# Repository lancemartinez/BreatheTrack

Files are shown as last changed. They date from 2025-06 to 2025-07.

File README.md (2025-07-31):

# BreatheTrack

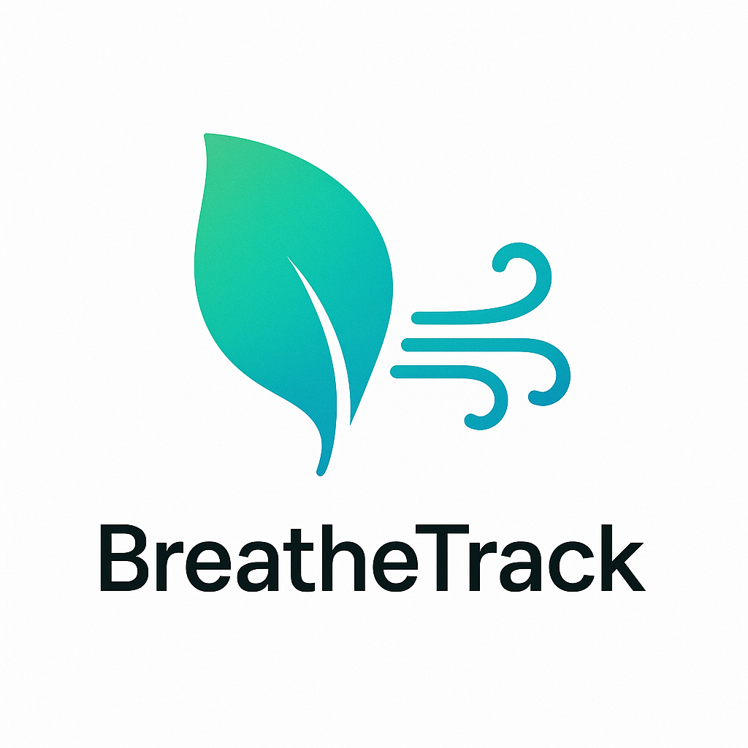
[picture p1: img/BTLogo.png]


## Prototype 1
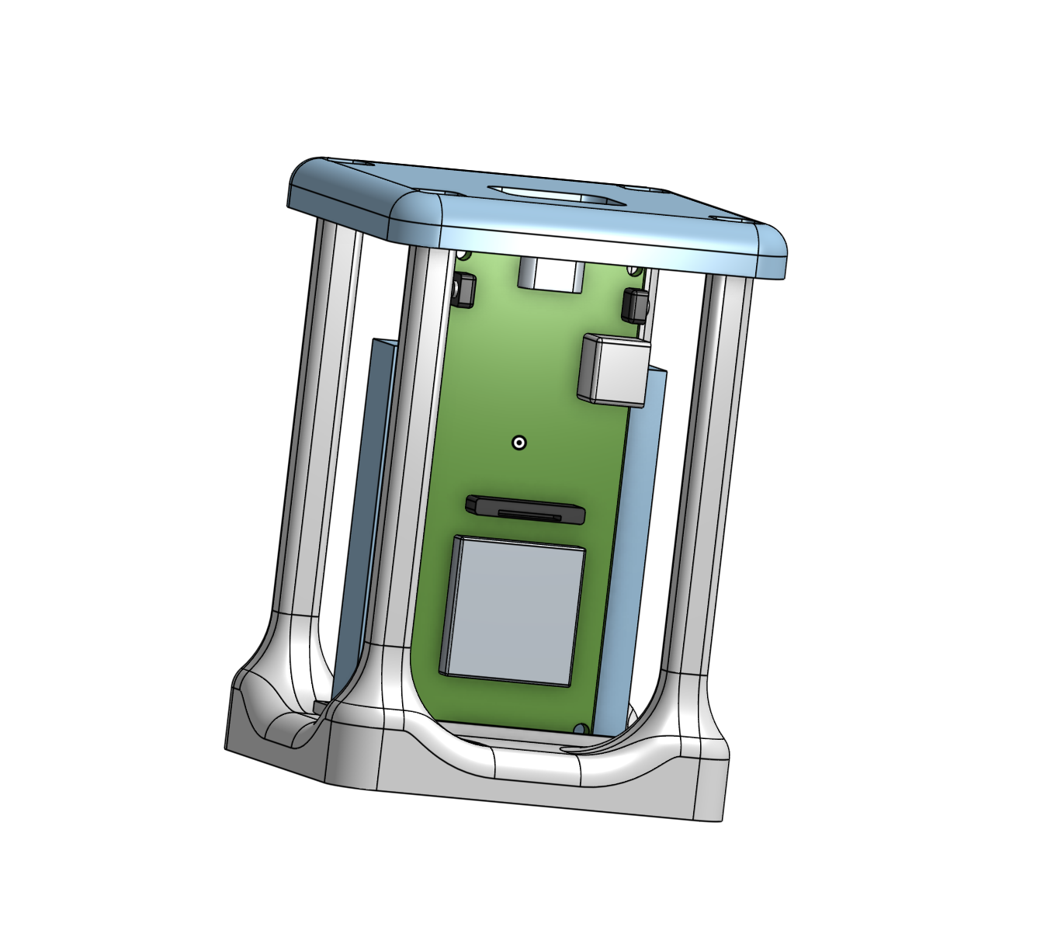
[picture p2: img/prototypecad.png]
CAD


## Assembled Prototype 1 
IRL

## Prototype 2

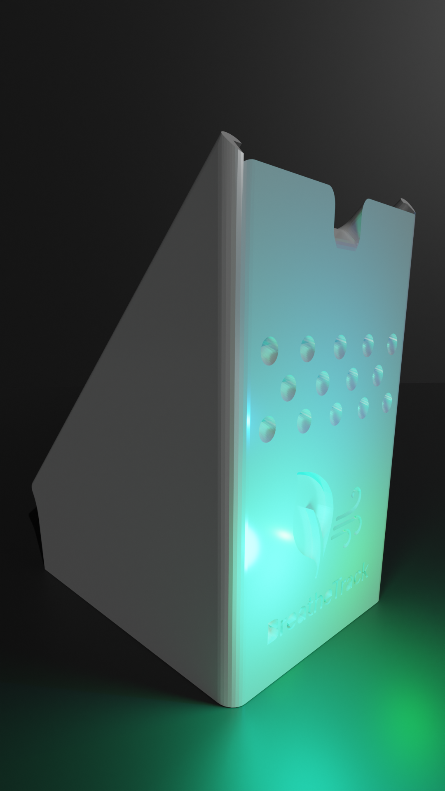
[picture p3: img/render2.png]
Render


## Bill of Materials (BOM)

| Component | Quantity | Price Estimate | Link |
|---|---|---|---|
| PCB | 1 | $60 | [JLCPCB](https://jlcpcb.com) |
| 6V 1W Solar Cell | 5 | $16 | [Amazon](https://www.amazon.com/gp/product/B0BML3PR4Z/ref=ox_sc_act_title_1?smid=A2MJCDED57HY1D&th=1) |
| MakerFocus ESP32 LoRa V3 Dev Board (with 2x SX1262 + 2x Battery) | 1 | $53 | [Amazon](https://www.amazon.com/gp/product/B0DMSGL2DC/ref=ox_sc_act_title_1?smid=A1N6DLY3NQK2VM&th=1) |
| Solar Panel Power Manager | 1 | $14 | [Amazon](https://www.amazon.com/gp/product/B07MML4YJV/ref=ox_sc_act_title_4?smid=A2EH5PO307BR7O&psc=1) |
| Breadboard, Resistors, LEDs Kit | 1 | $10 | [Amazon](https://www.amazon.com/dp/B01ERP6WL4) |
| Soldering Iron | 1 | $9 | [Amazon](https://www.amazon.com/Soldering-Welding-Portable-Electric-Repairing/dp/B098JD8HD3) |
| Total | 10 | $162 | N/A |

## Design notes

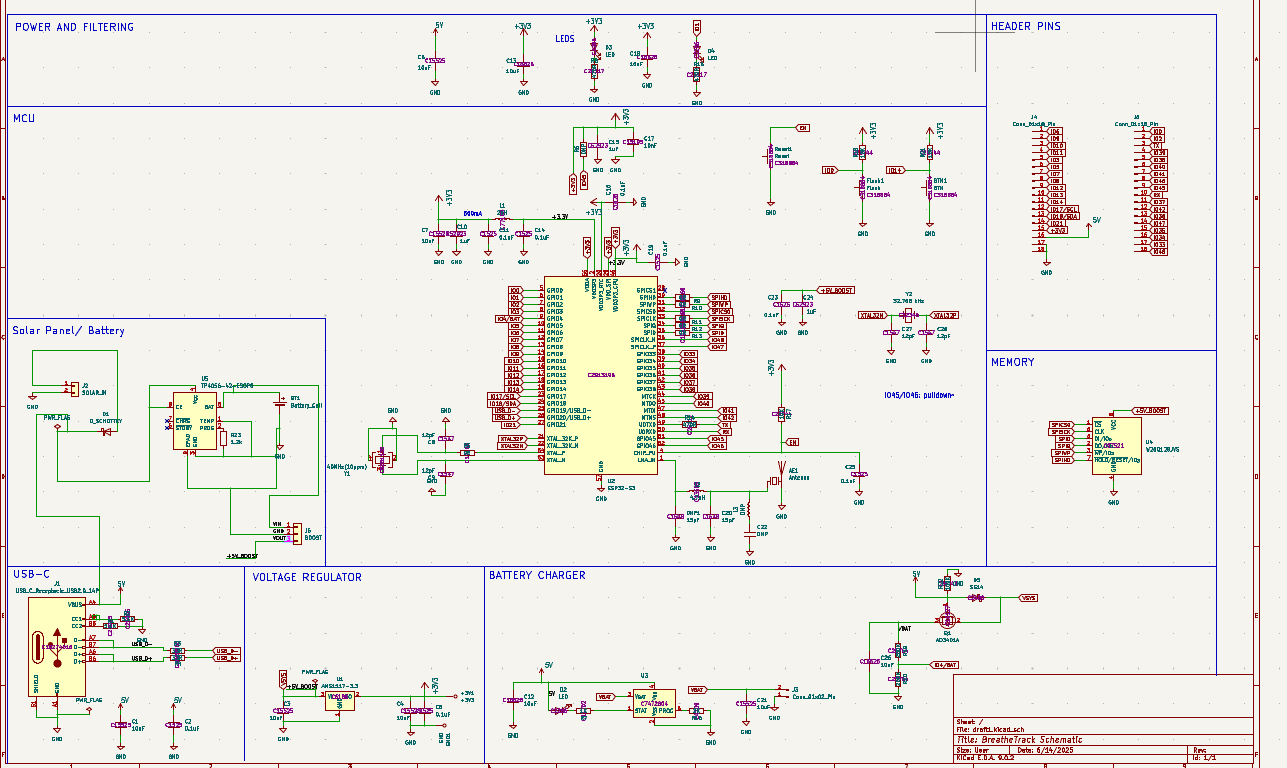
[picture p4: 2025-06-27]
img/schematic.png

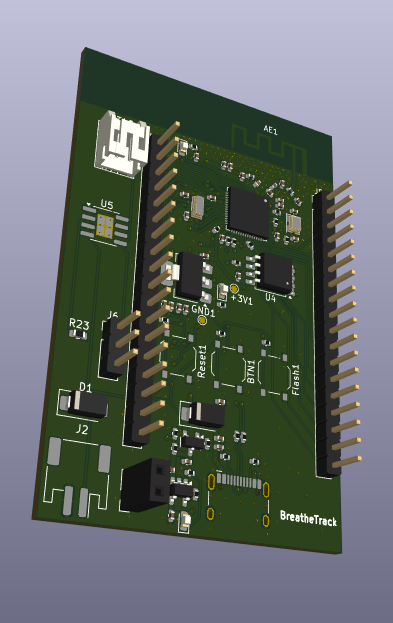
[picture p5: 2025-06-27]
img/BreatheTrackBoard.png

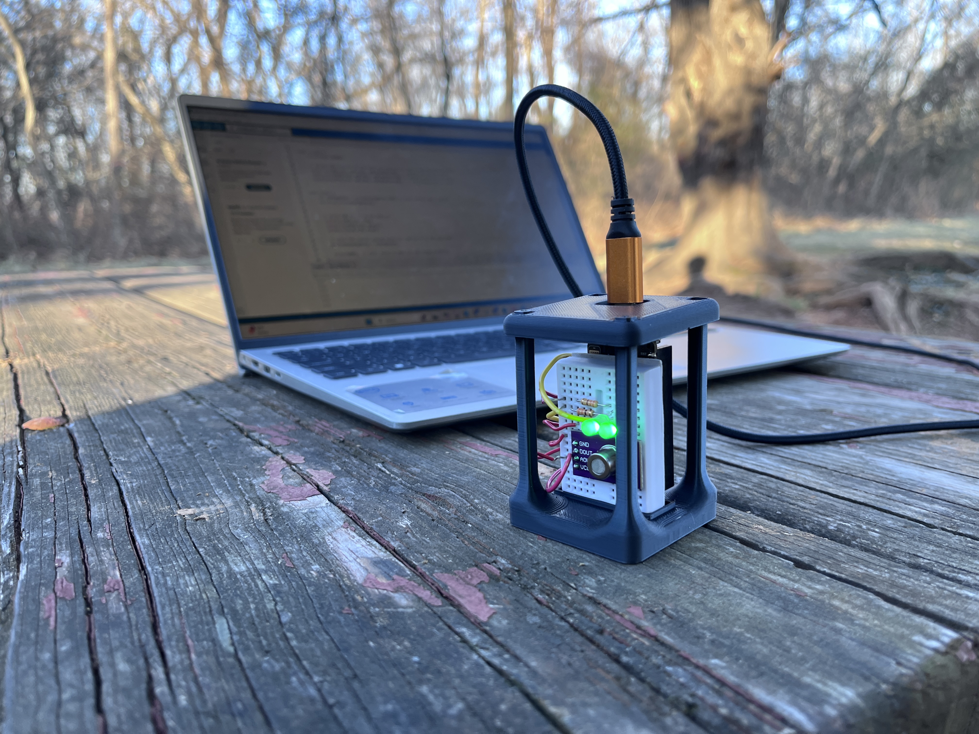
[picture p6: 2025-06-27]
img/prototype.JPG

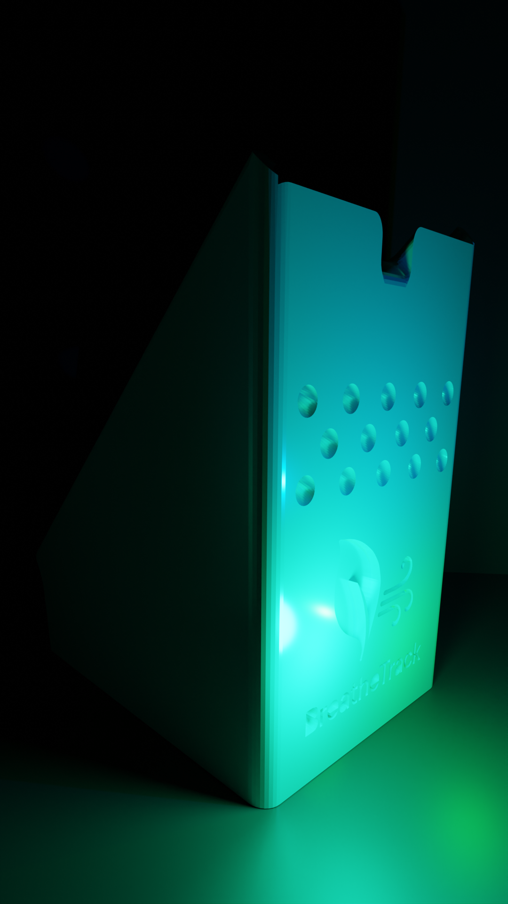
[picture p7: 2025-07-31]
img/render.png

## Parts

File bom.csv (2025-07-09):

Component | Quantity | Price Estimate | Link
PCB | 1 | $60 | https://jlcpcb.com
6V 1W Solar Cell | 5 | $16 | https://www.amazon.com/gp/product/B0BML3PR4Z/ref=ox_sc_act_title_1?smid=A2MJCDED57HY1D&th=1
MakerFocus ESP32 LoRa V3 Dev Board (with 2x SX1262 + 2x Battery) | 1 | $53 | https://www.amazon.com/gp/product/B0DMSGL2DC/ref=ox_sc_act_title_1?smid=A1N6DLY3NQK2VM&th=1
Solar Panel Power Manager | 1 | $14 | https://www.amazon.com/gp/product/B07MML4YJV/ref=ox_sc_act_title_4?smid=A2EH5PO307BR7O&psc=1
Breadboard, Resistors, LEDs Kit | 1 | $10 | https://www.amazon.com/dp/B01ERP6WL4
Soldering Iron | 1 | $9 | https://www.amazon.com/Soldering-Welding-Portable-Electric-Repairing/dp/B098JD8HD3
Total | 10 | $162 | N/A

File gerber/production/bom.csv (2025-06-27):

Designator | Footprint | Quantity | Value | LCSC Part #
+3V1 | TestPoint_Pad_D1.0mm | 1 | +3V3
AE1 | Texas_SWRA117D_2.4GHz_Left | 1 | Antenna
BT1 | JST_PH_S2B-PH-K_1x02_P2.00mm_Horizontal | 1 | Battery_Cell
BTN1 | SW_Push_1P1T_XKB_TS-1187A | 1 | BTN | C318884
C1, C12, C13, C18, C21, C26, C3, C4, C6, C7 | 0402 | 10 | 10uF | C15525
C10, C15, C24 | 0402 | 3 | 1uF | C52923
C11, C14, C16, C19, C2, C23, C25, C5 | 0402 | 8 | 0.1uF | C1525
C17 | 0402 | 1 | 10nF | C15195
C20, DNP1 | 0402 | 2 | 15pF | C1548
C22, L3 | 0402 | 2 | DNP
C27, C28, C8, C9 | 0402 | 4 | 12pF | C1547
D1 | D_SMA | 1 | D_SCHOTTKY
D2, D3, D4 | 0603 | 3 | LED | C2286
D5 | D_SMA | 1 | SS14 | C2480
FLASH1 | SW_Push_1P1T_XKB_TS-1187A | 1 | Flash | C318884
GND1 | TestPoint_Pad_D1.0mm | 1 | GND
J1 | USB_C_Receptacle_HCTL_HC-TYPE-C-16P-01A | 1 | USB_C_Receptacle_USB2.0_14P | C19274016
J2 | JST_PH_S2B-PH-SM4-TB_1x02-1MP_P2.00mm_Horizontal | 1 | SOLAR_IN
J3 | PinSocket_1x02_P2.54mm_Vertical | 1 | Conn_01x02_Pin
J4, J5 | PinHeader_1x18_P2.54mm_Vertical | 2 | Conn_01x18_Pin
J6 | PinHeader_1x03_P2.54mm_Vertical | 1 | BOOST
L1 | 0402 | 1 | 2nH | C77103
L2 | 0402 | 1 | 4.7nH | C13595
Q1 | SOT-23 | 1 | AO3401A | C15127
R1, R2 | 0402 | 2 | 5.1K | C25905
R10, R11, R12, R13, R5, R9 | 0402 | 6 | 0R | C17168
R14, R15, R8 | 0402 | 3 | 470R | C25117
R16 | 0402 | 1 | 2K | C4109
R17, R18, R21 | 0402 | 3 | 10K | C25744
R19, R20 | 0402 | 2 | 200K | C25764
R22 | 0402 | 1 | 100K | C25741
R23 | 0603 | 1 | 1.2k
R3, R4 | 0402 | 2 | 33R | C25105
R6 | 0402 | 1 | DNP
R7 | 0402 | 1 | 1K | C11702
RESET1 | SW_Push_1P1T_XKB_TS-1187A | 1 | Reset | C318884
U1 | SOT-223-3_TabPin2 | 1 | AMS1117-3.3 | C6186
U2 | QFN-56-1EP_7x7mm_P0.4mm_EP4x4mm | 1 | ESP32-S3 | C2913194
U3 | SOT-23-5 | 1 | MCP73831-2-OT | C7472804
U4 | SOIC-8_5.3x5.3mm_P1.27mm | 1 | W25Q128JVS | C97521
U5 | SOIC-8-1EP_3.9x4.9mm_P1.27mm_EP2.41x3.3mm_ThermalVias | 1 | TP4056-42-ESOP8
Y1 | Crystal_SMD_2520-4Pin_2.5x2.0mm | 1 | 40MHz(10ppm) | C5261125
Y2 | Crystal_SMD_3215-2Pin_3.2x1.5mm | 1 | 32.768 kHz | C32346

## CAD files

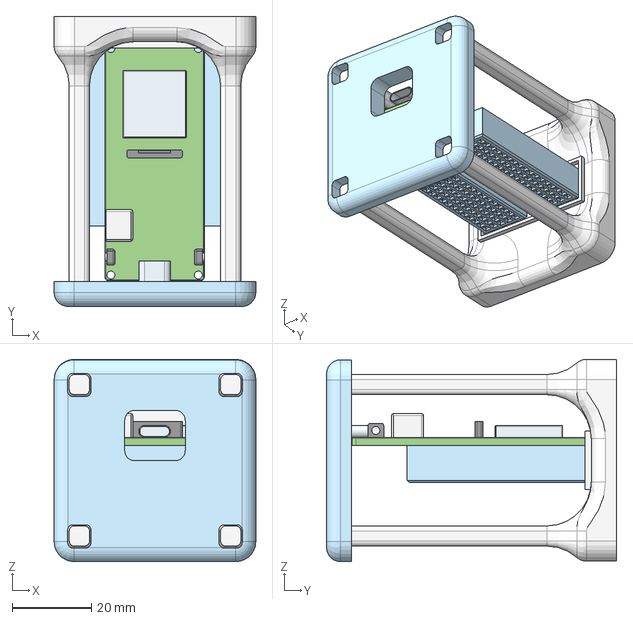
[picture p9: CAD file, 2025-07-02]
cad/full.step
50.8 x 73.0 x 50.9 mm
FireBeetle ESP32

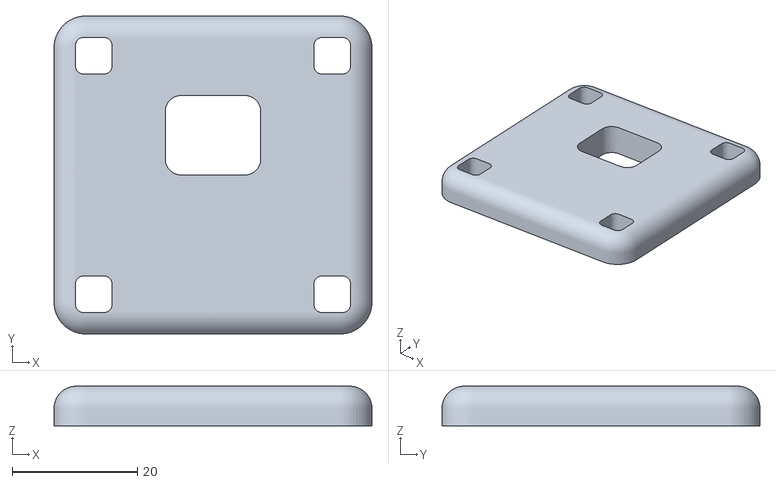
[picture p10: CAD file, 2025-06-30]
cad/top.stl
50.8 x 50.8 x 6.35

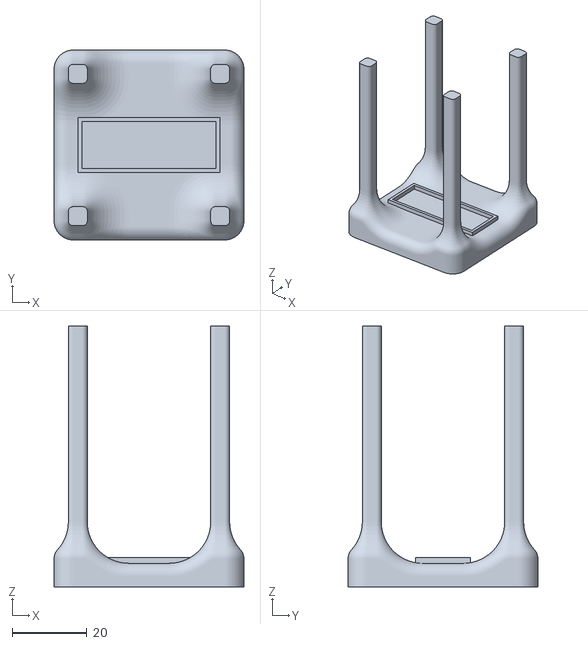
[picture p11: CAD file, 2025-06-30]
cad/base.stl
50.8 x 50.8 x 69.8

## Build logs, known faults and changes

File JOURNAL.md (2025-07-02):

---
title: "BreatheTrack Solar‑Powered PCB Design"
author: "Lance Martinez"
description: "Solar panel, battery charger, protection, and boost stages to power our custom ESP32‑AQI sensor board from sunlight alone."
created_at: "2025-06-14"
---

## Total Time Spent: ~ 16.5 hours   

### June 3
Time Spent: ~6 hours  

Today, I focused on building the core ESP32 section of our custom PCB in KiCad 9.0. I added all the main headers, supporting components, and filtered power supply for the ESP32. This includes decoupling capacitors, pull-up resistors, and the external crystal to keep the ESP32 stable. This was my first time building something like this, so I carefully checked all the pin assignments and made sure everything matched the microcontroller datasheet.

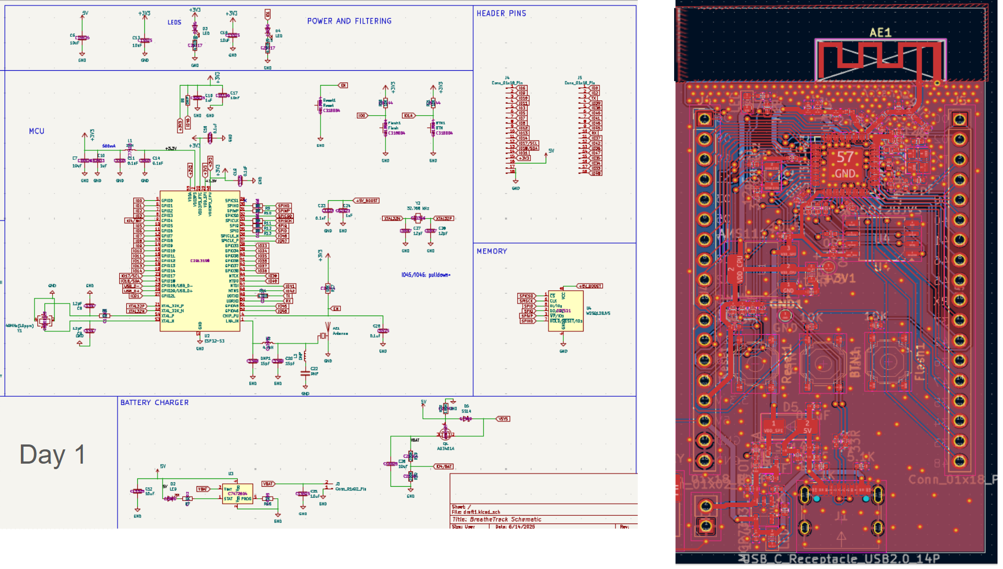
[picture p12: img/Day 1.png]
Day 1


### June 5
Time Spent: ~3 hours  
Today I started adding power management to the board. I wired in the solar panel input with a Schottky diode, connected it to a TP4056 charging IC with battery protection, and then added a boost converter to step up the voltage for the ESP32. I also placed the JST connectors for both the battery and solar panel. Getting all the power paths correct took some troubleshooting, especially routing from the solar panel through the diode into the charger. I made sure everything would pass power safely and avoid battery drain through the panel at night.

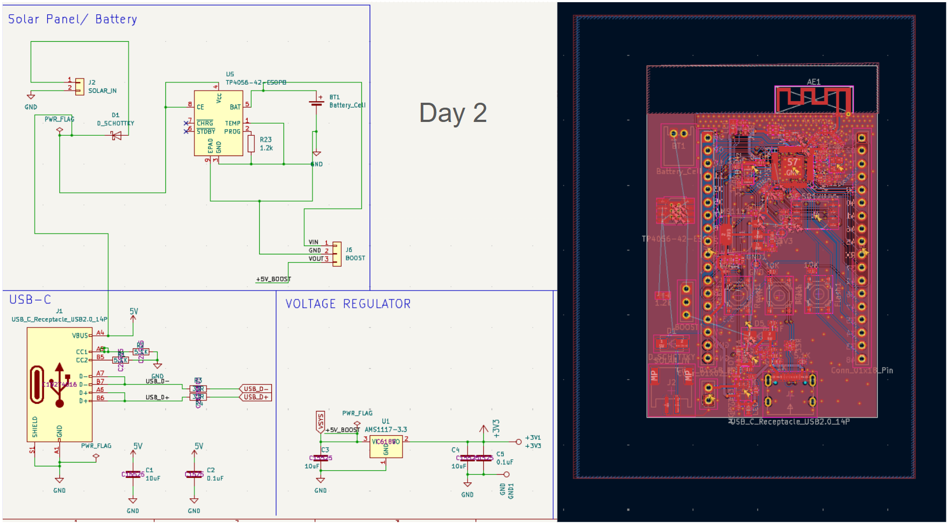
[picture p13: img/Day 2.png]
Day 2


### June 10
Time Spent: ~3 hours  
This day was all about finishing the wiring. I routed power and signal lines for the full system, including the ESP32, USB port, and power modules. I carefully laid out the boost converter output to feed into the ESP32's 5V input rail and added silkscreen labels for clarity. I also added vias and filled in ground planes to reduce noise and improve current return paths. The PCB was becoming more complete and compact, and I started preparing for design rule checks.

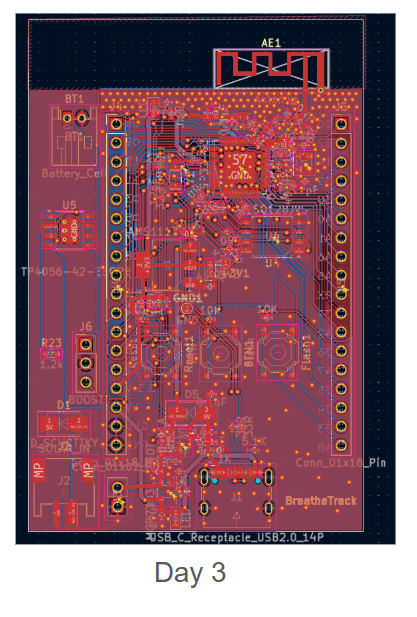
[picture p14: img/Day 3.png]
Day 3


### June 12

Time Spent: ~1.5 hours   

Today, I finalized the 3D-printed enclosure for our system. This case securely holds the ESP32, AQI sensor, and the breadboard containing the circuitry. The design includes precision slots that apply just enough pressure to hold the board firmly in place. The top and bottom covers snap into the frame and leave space for airflow, allowing accurate environmental readings. Building this physical housing was a major step toward making our device ready for outdoor areas.

Prototype CAD

## June 14
Time Spent: ~3 hours  
Today I fixed the final DRC errors and reviewed the board for manufacturing. I checked footprint sizes, confirmed that clearances were good, and ran the 3D viewer for the first time to confirm everything looked right. Seeing the board in 3D helped catch small alignment issues, and I made final tweaks to trace widths and placements. Now, the board is ready to export Gerber files and send for fabrication!

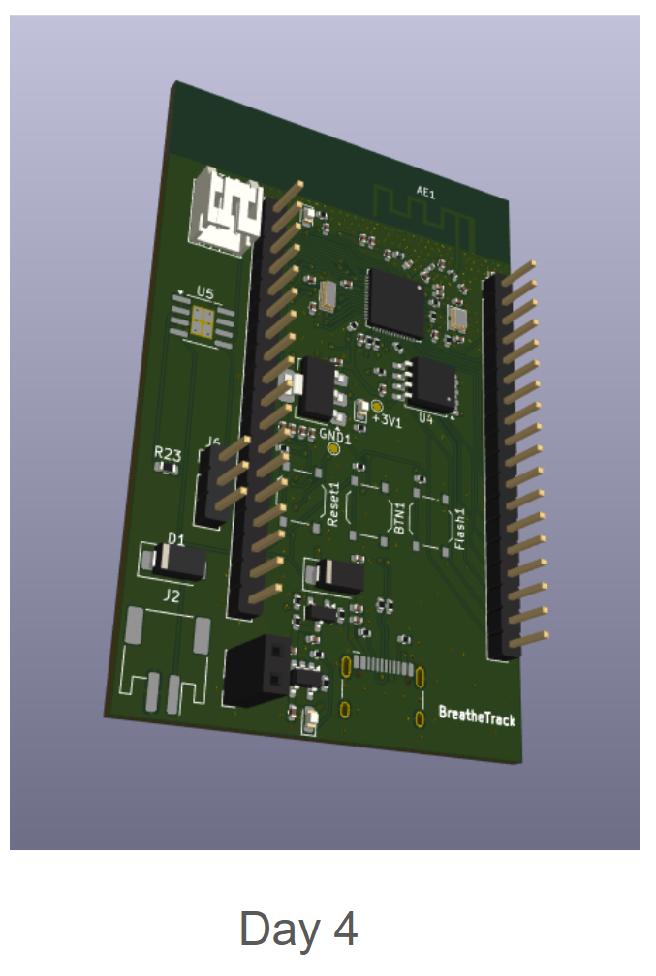
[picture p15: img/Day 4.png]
Day 4


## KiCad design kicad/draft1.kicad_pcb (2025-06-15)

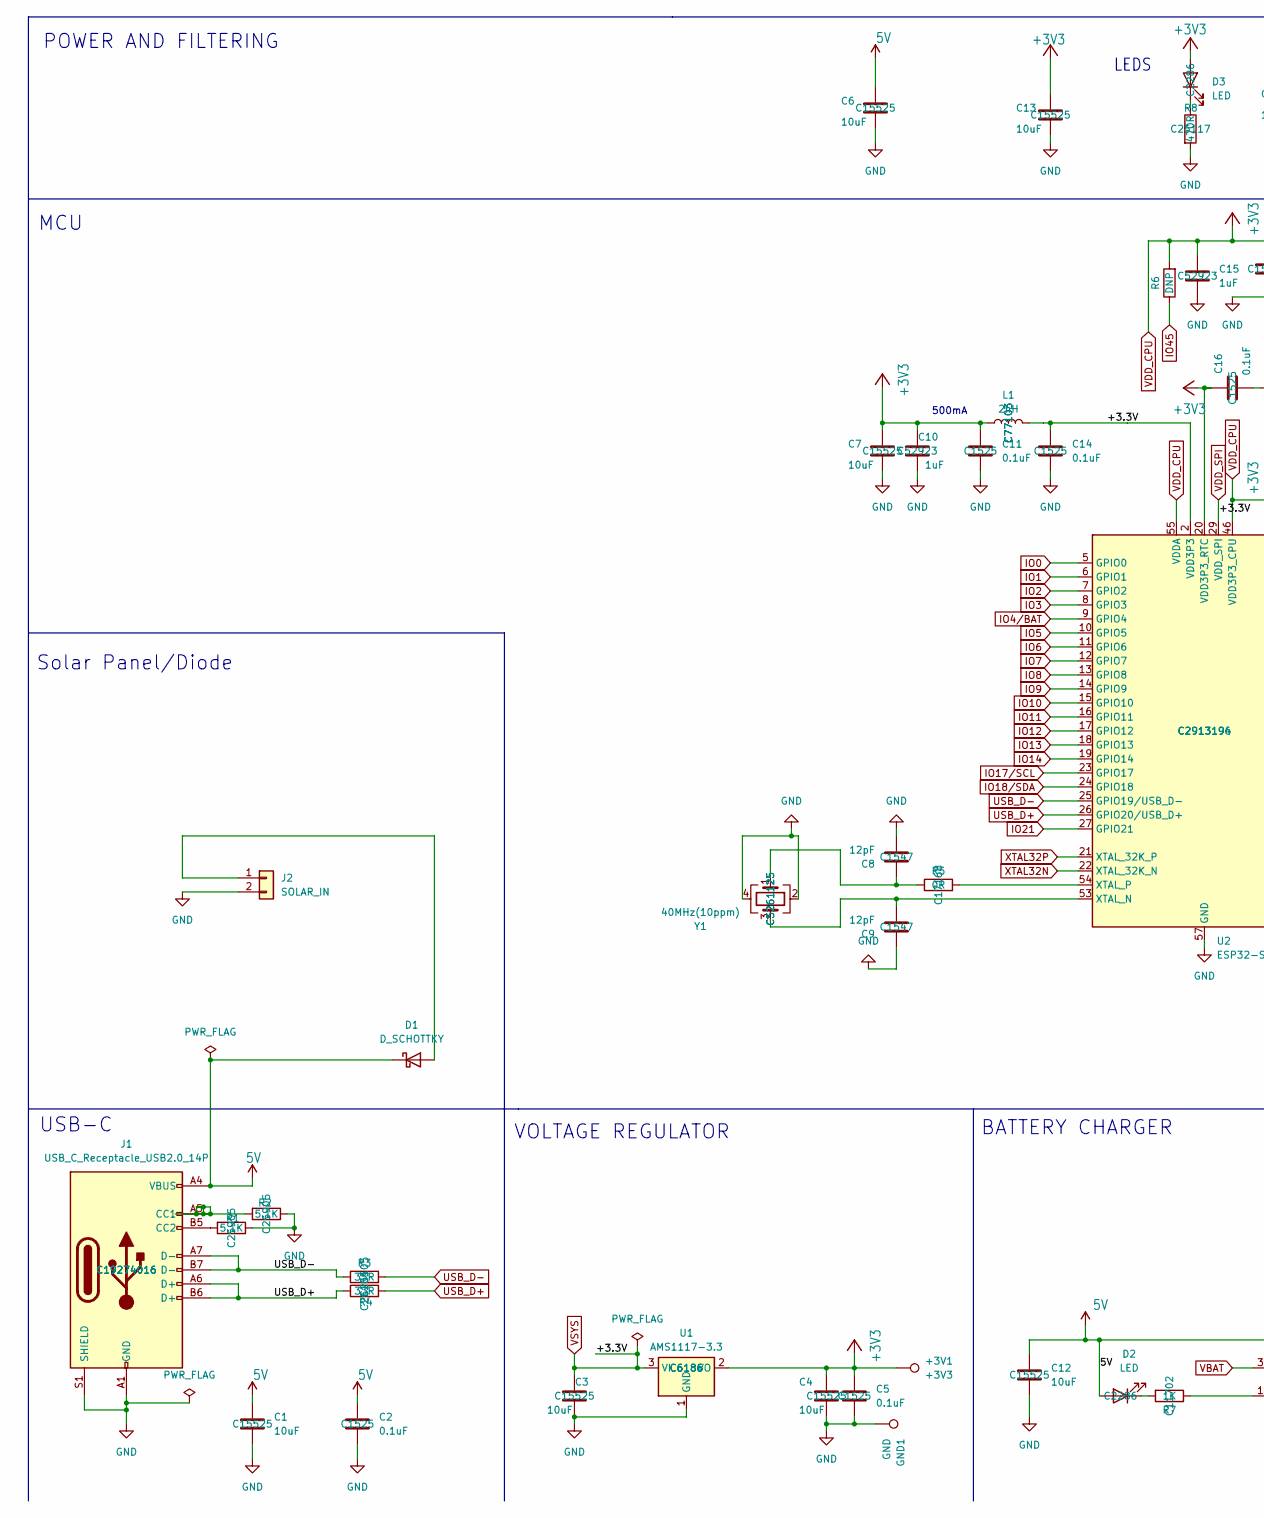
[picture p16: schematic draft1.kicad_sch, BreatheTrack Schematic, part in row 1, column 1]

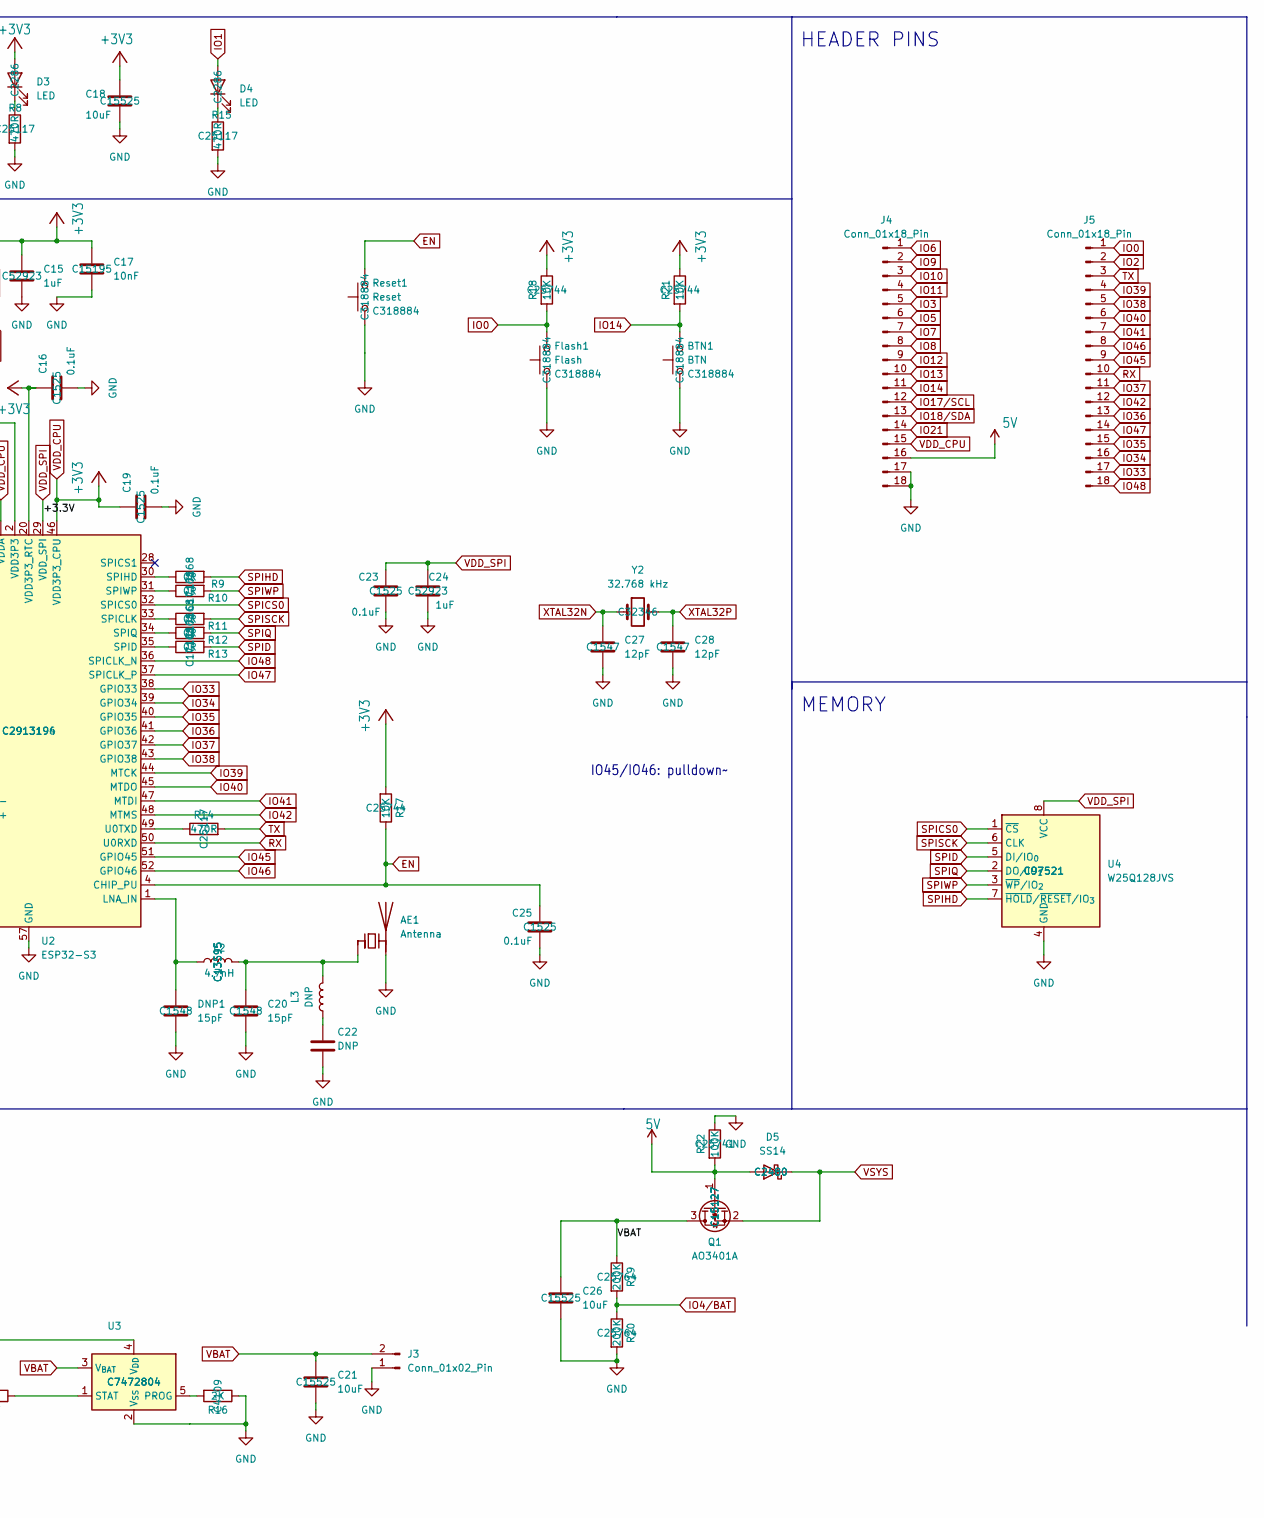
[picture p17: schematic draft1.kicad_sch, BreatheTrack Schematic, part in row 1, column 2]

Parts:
+3V1: +3V3; TestPoint_Pad_D1.0mm
AE1: Antenna; Texas_SWRA117D_2.4GHz_Left
BTN1: BTN; SW_Push_1P1T_XKB_TS-1187A; MNF PART NUMBER C318884; LCSC C318884
C1, C3, C4, C6, C7, C12, C13, C18, C21, C26: 10uF; C_0402_1005Metric; MNF PART NUMBER C15525; LCSC C15525
C2, C5, C11, C14, C16, C19, C23, C25: 0.1uF; C_0402_1005Metric; MNF PART NUMBER C1525; LCSC C1525
C8, C9, C27, C28: 12pF; C_0402_1005Metric; MNF PART NUMBER C1547; LCSC C1547
C10, C15, C24: 1uF; C_0402_1005Metric; MNF PART NUMBER C52923; LCSC C52923
C17: 10nF; C_0402_1005Metric; MNF PART NUMBER C15195; LCSC C15195
C20: 15pF; C_0402_1005Metric; MNF PART NUMBER C1548; LCSC C1548
C22: DNP; C_0402_1005Metric
D1: D_SCHOTTKY; D_SMA
D2, D3, D4: LED; LED_0603_1608Metric; MNF PART NUMBER C2286; LCSC C2286
D5: SS14; D_SMA; MNF PART NUMBER C2480; LCSC C2480
DNP1: 15pF; C_0402_1005Metric; MNF PART NUMBER C1548; LCSC C1548
Flash1: Flash; SW_Push_1P1T_XKB_TS-1187A; MNF PART NUMBER C318884; LCSC C318884
GND1: GND; TestPoint_Pad_D1.0mm
J1: USB_C_Receptacle_USB2.0_14P; USB_C_Receptacle_HCTL_HC-TYPE-C-16P-01A; MNF PART NUMBER C19274016; LCSC C19274016
J2: SOLAR_IN; JST_PH_S2B-PH-SM4-TB_1x02-1MP_P2.00mm_Horizontal
J3: Conn_01x02_Pin; PinSocket_1x02_P2.54mm_Vertical
J4, J5: Conn_01x18_Pin; PinHeader_1x18_P2.54mm_Vertical
L1: 2nH; L_0402_1005Metric; MNF PART NUMBER C77103; LCSC C77103
L2: 4.7nH; L_0402_1005Metric; MNF PART NUMBER C13595; LCSC C13595
L3: DNP; L_0402_1005Metric
Q1: AO3401A; SOT-23; MNF PART NUMBER C15127; LCSC C15127
R1, R2: 5.1K; R_0402_1005Metric; MNF PART NUMBER C25905; LCSC C25905
R3, R4: 33R; R_0402_1005Metric; MNF PART NUMBER C25105; LCSC C25105
R5, R9, R10, R11, R12, R13: 0R; R_0402_1005Metric; MNF PART NUMBER C17168; LCSC C17168
R6: DNP; R_0402_1005Metric
R7: 1K; R_0402_1005Metric; MNF PART NUMBER C11702; LCSC C11702
R8, R14, R15: 470R; R_0402_1005Metric; MNF PART NUMBER C25117; LCSC C25117
R16: 2K; R_0402_1005Metric; MNF PART NUMBER C4109; LCSC C4109
R17, R18, R21: 10K; R_0402_1005Metric; MNF PART NUMBER C25744; LCSC C25744
R19, R20: 200K; R_0402_1005Metric; MNF PART NUMBER C25764; LCSC C25764
R22: 100K; R_0402_1005Metric; MNF PART NUMBER C25741; LCSC C25741
Reset1: Reset; SW_Push_1P1T_XKB_TS-1187A; MNF PART NUMBER C318884; LCSC C318884
U1: AMS1117-3.3; SOT-223-3_TabPin2; MNF PART NUMBER C6186; LCSC C6186
U2: ESP32-S3; QFN-56-1EP_7x7mm_P0.4mm_EP4x4mm; MNF PART NUMBER C2913196; LCSC C2913194
U3: MCP73831-2-OT; SOT-23-5; MNF PART NUMBER C7472804; LCSC C7472804
U4: W25Q128JVS; SOIC-8_5.3x5.3mm_P1.27mm; MNF PART NUMBER C97521; LCSC C97521
Y1: 40MHz(10ppm); Crystal_SMD_2520-4Pin_2.5x2.0mm; MNF PART NUMBER C5261125; LCSC C5261125
Y2: 32.768 kHz; Crystal_SMD_3215-2Pin_3.2x1.5mm; MNF PART NUMBER C32346; LCSC C32346

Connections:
5V: C1.1, C2.1, C6.1, C12.1, D1.1 (K), D2.2 (A), D5.2 (A), J1.A4 (VBUS), J1.A9 (VBUS), J1.B4 (VBUS), J1.B9 (VBUS), J4.16, Q1.1 (G), R22.2, U3.4 (V_{DD})
EN: C25.1, R17.1, Reset1.2, U2.4 (CHIP_PU)
GND: AE1.2 (PCB_Trace), BTN1.1, C1.2, C2.2, C3.2, C4.2, C5.2, C6.2, C7.2, C8.2, C9.1, C10.2, C11.2, C12.2, C13.2, C14.2, C15.2, C16.2, C17.2, C18.2, C19.2, C20.2, C21.2, C22.2, C23.2, C24.2, C25.2, C26.2, C27.2, C28.2, DNP1.2, Flash1.1, GND1.1, J1.A1 (GND), J1.A12 (GND), J1.B1 (GND), J1.B12 (GND), J1.S1 (SHIELD), J2.2, J3.1, J4.17, J4.18, R1.1, R2.1, R8.2, R15.2, R16.1, R20.2, R22.1, Reset1.1, U1.1 (GND), U2.57 (GND), U3.2 (V_{SS}), U4.4 (GND), Y1.2, Y1.4
IO0: Flash1.2, J5.1, R18.2, U2.5 (GPIO0)
IO1: D4.2 (A), U2.6 (GPIO1)
IO2: J5.2, U2.7 (GPIO2)
IO3: J4.5, U2.8 (GPIO3)
IO4/BAT: R19.2, R20.1, U2.9 (GPIO4)
IO5: J4.6, U2.10 (GPIO5)
IO6: J4.1, U2.11 (GPIO6)
IO7: J4.7, U2.12 (GPIO7)
IO8: J4.8, U2.13 (GPIO8)
IO9: J4.2, U2.14 (GPIO9)
IO10: J4.3, U2.15 (GPIO10)
IO11: J4.4, U2.16 (GPIO11)
IO12: J4.9, U2.17 (GPIO12)
IO13: J4.10, U2.18 (GPIO13)
IO14: BTN1.2, J4.11, R21.2, U2.19 (GPIO14)
IO17/SCL: J4.12, U2.23 (GPIO17)
IO18/SDA: J4.13, U2.24 (GPIO18)
IO21: J4.14, U2.27 (GPIO21)
IO33: J5.17, U2.38 (GPIO33)
IO34: J5.16, U2.39 (GPIO34)
IO35: J5.15, U2.40 (GPIO35)
IO36: J5.13, U2.41 (GPIO36)
IO37: J5.11, U2.42 (GPIO37)
IO38: J5.5, U2.43 (GPIO38)
IO39: J5.4, U2.44 (MTCK)
IO40: J5.6, U2.45 (MTDO)
IO41: J5.7, U2.47 (MTDI)
IO42: J5.12, U2.48 (MTMS)
IO45: J5.9, R6.1, U2.51 (GPIO45)
IO46: J5.8, U2.52 (GPIO46)
IO47: J5.14, U2.37 (SPICLK_P)
IO48: J5.18, U2.36 (SPICLK_N)
unnamed: AE1.1 (FEED), C20.1, L2.2, L3.2
unnamed: C8.1, R5.1, Y1.1
unnamed: C22.1, L3.1
unnamed: D1.2 (A), J2.1
unnamed: D2.1 (K), R7.2
unnamed: D3.1 (K), R8.1
unnamed: D4.1 (K), R15.1
unnamed: J1.A5 (CC1), R2.2
unnamed: J1.B5 (CC2), R1.2
unnamed: DNP1.1, L2.1, U2.1 (LNA_IN)
unnamed: R11.1, U2.33 (SPICLK)
unnamed: R13.1, U2.35 (SPID)
unnamed: R9.1, U2.30 (SPIHD)
unnamed: R12.1, U2.34 (SPIQ)
unnamed: R10.1, U2.31 (SPIWP)
unnamed: R14.1, U2.49 (U0TXD)
unnamed: C9.2, U2.53 (XTAL_N), Y1.3
unnamed: R5.2, U2.54 (XTAL_P)
unnamed: R16.2, U3.5 (PROG)
unnamed: R7.1, U3.1 (STAT)
RX: J5.10, U2.50 (U0RXD)
SPICS0: U2.32 (SPICS0), U4.1 (~CS)
SPID: R13.2, U4.5 (DI/IO_{0})
SPIHD: R9.2, U4.7 (~HOLD/~RESET/IO_{3})
SPIQ: R12.2, U4.2 (DO/IO_{1})
SPISCK: R11.2, U4.6 (CLK)
SPIWP: R10.2, U4.3 (~WP/IO_{2})
TX: J5.3, R14.2
USB_D+: J1.A6 (D+), J1.B6 (D+), R4.1, R4.2, U2.26 (GPIO20/USB_D+)
USB_D-: J1.A7 (D-), J1.B7 (D-), R3.1, R3.2, U2.25 (GPIO19/USB_D-)
VBAT: C21.1, C26.1, J3.2, Q1.3 (D), R19.1, U3.3 (V_{BAT})
VDD_CPU: +3V1.1, C4.1, C5.1, C7.1, C10.1, C11.1, C13.1, C15.1, C16.1, C17.1, C18.1, C19.1, D3.2 (A), J4.15, L1.1, R6.2, R17.2, R18.1, R21.1, U1.2 (VO), U2.20 (VDD3P3_RTC), U2.46 (VDD3P3_CPU), U2.55 (VDDA), U2.56 (VDDA)
VDD_SPI: C3.1, C14.1, C23.1, C24.1, D5.1 (K), L1.2, Q1.2 (S), U1.3 (VI), U2.2 (VDD3P3), U2.3 (VDD3P3), U2.29 (VDD_SPI), U4.8 (VCC)
XTAL32N: C27.1, U2.22 (XTAL_32K_N), Y2.1
XTAL32P: C28.1, U2.21 (XTAL_32K_P), Y2.2

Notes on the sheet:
Solar Panel/Diode
500mA
MCU
USB-C
BATTERY CHARGER
MEMORY
VOLTAGE REGULATOR
IO45/IO46: pulldown~~{}
POWER AND FILTERING
HEADER PINS
LEDS

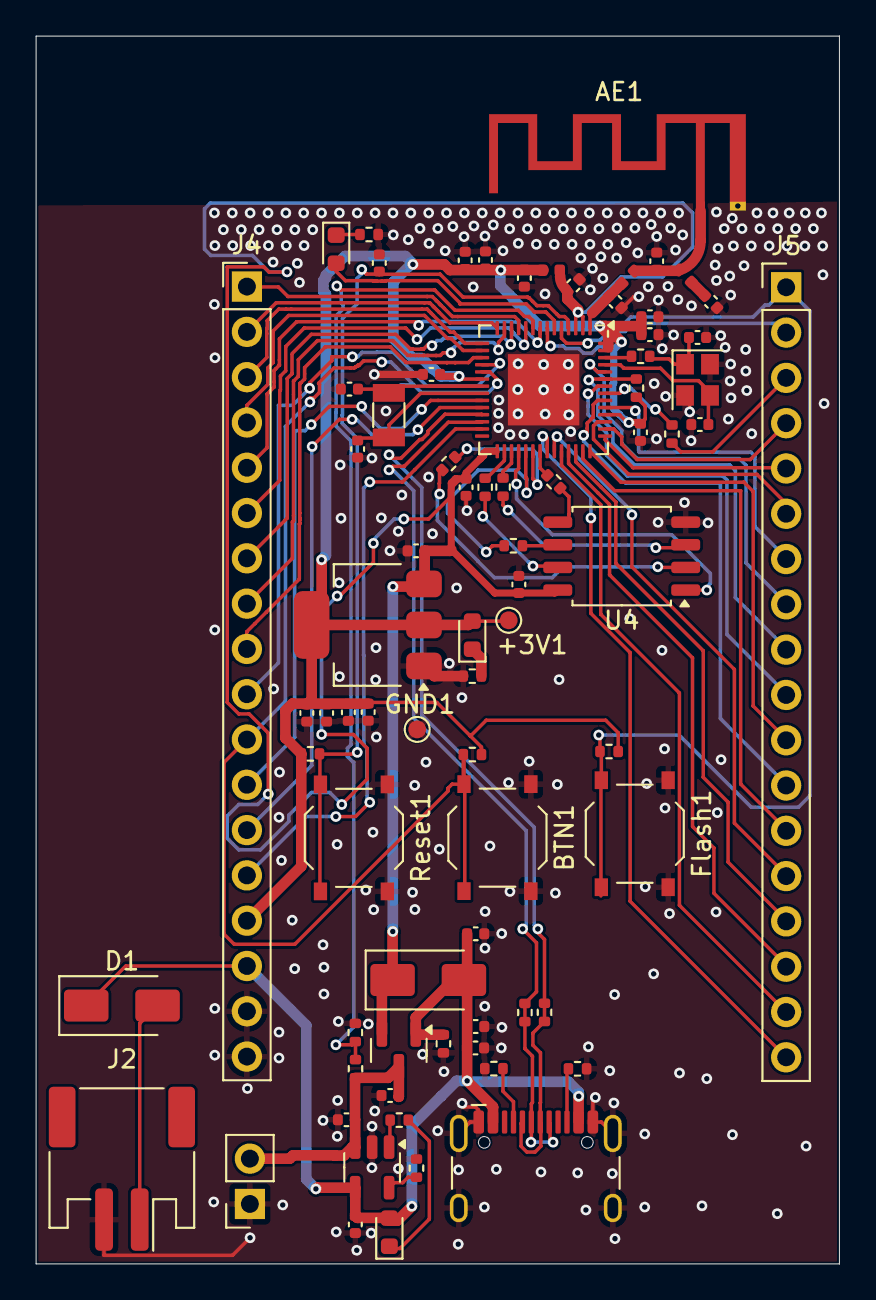
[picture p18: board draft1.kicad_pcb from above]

Board: 4 copper layers, 45.1 x 68.8 mm, 77 parts (0 on the bottom side), 70 nets.

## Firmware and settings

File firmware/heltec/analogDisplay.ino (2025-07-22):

#include <Wire.h>               
#include "HT_SSD1306Wire.h"

static SSD1306Wire  display(0x3c, 500000, SDA_OLED, SCL_OLED, GEOMETRY_128_64, RST_OLED); 
const int analogPin = 7;
#define DEMO_DURATION 3000
typedef void (*Demo)(void);

int demoMode = 0;
int counter = 1;

void setup() {
  Serial.begin(115200);
  Serial.println();
  Serial.println();
  VextON();
  delay(100);
  display.init();
  display.setFont(ArialMT_Plain_24);
}

void VextON(void)
{
  pinMode(Vext,OUTPUT);
  digitalWrite(Vext, LOW);
}

void VextOFF(void) 
{
  pinMode(Vext,OUTPUT);
  digitalWrite(Vext, HIGH);
}

void readDisplayAQI(){
  int analogValue = analogRead(analogPin);
  Serial.print("Analog Value: ");
  Serial.println(analogValue);
  display.setTextAlignment(TEXT_ALIGN_CENTER);
  display.drawString(64, 26, String(analogValue)); 

}
Demo demos[] = {readDisplayAQI};
int demoLength = (sizeof(demos) / sizeof(Demo));
long timeSinceLastModeSwitch = 0;

void loop() {
  display.clear();
  demos[0]();
  display.setTextAlignment(TEXT_ALIGN_RIGHT);
  display.drawString(10, 128, String(millis()));
  display.display();
  delay(1000);

}

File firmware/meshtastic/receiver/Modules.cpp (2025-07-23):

#include "configuration.h"
#include "AqiReceiverModule.h"
AqiReceiverModule *aqiReceiverModule = nullptr;
#if !MESHTASTIC_EXCLUDE_INPUTBROKER
#include "buzz/BuzzerFeedbackThread.h"
#include "input/ExpressLRSFiveWay.h"
#include "input/InputBroker.h"
#include "input/RotaryEncoderInterruptImpl1.h"
#include "input/SerialKeyboardImpl.h"
#include "input/TrackballInterruptImpl1.h"
#include "input/UpDownInterruptImpl1.h"
#include "modules/SystemCommandsModule.h"
#if !MESHTASTIC_EXCLUDE_I2C
#include "input/cardKbI2cImpl.h"
#endif
#include "input/kbMatrixImpl.h"
#endif
#if !MESHTASTIC_EXCLUDE_PKI
#include "KeyVerificationModule.h"
#endif
#if !MESHTASTIC_EXCLUDE_ADMIN
#include "modules/AdminModule.h"
#endif
#if !MESHTASTIC_EXCLUDE_ATAK
#include "modules/AtakPluginModule.h"
#endif
#if !MESHTASTIC_EXCLUDE_CANNEDMESSAGES
#include "modules/CannedMessageModule.h"
#endif
#if !MESHTASTIC_EXCLUDE_DETECTIONSENSOR
#include "modules/DetectionSensorModule.h"
#endif
#if !MESHTASTIC_EXCLUDE_NEIGHBORINFO
#include "modules/NeighborInfoModule.h"
#endif
#if !MESHTASTIC_EXCLUDE_NODEINFO
#include "modules/NodeInfoModule.h"
#endif
#if !MESHTASTIC_EXCLUDE_GPS
#include "modules/PositionModule.h"
#endif
#if !MESHTASTIC_EXCLUDE_REMOTEHARDWARE
#include "modules/RemoteHardwareModule.h"
#endif
#if !MESHTASTIC_EXCLUDE_POWERSTRESS
#include "modules/PowerStressModule.h"
#endif
#include "modules/RoutingModule.h"
#include "modules/TextMessageModule.h"
#if !MESHTASTIC_EXCLUDE_TRACEROUTE
#include "modules/TraceRouteModule.h"
#endif
#if !MESHTASTIC_EXCLUDE_WAYPOINT
#include "modules/WaypointModule.h"
#endif
#if ARCH_PORTDUINO
#include "input/LinuxInputImpl.h"
#include "input/SeesawRotary.h"
#include "modules/Telemetry/HostMetrics.h"
#if !MESHTASTIC_EXCLUDE_STOREFORWARD
#include "modules/StoreForwardModule.h"
#endif
#endif
#if HAS_TELEMETRY
#include "modules/Telemetry/DeviceTelemetry.h"
#endif
#if HAS_SENSOR && !MESHTASTIC_EXCLUDE_ENVIRONMENTAL_SENSOR
#include "main.h"
#include "modules/Telemetry/AirQualityTelemetry.h"
#include "modules/Telemetry/EnvironmentTelemetry.h"
#include "modules/Telemetry/HealthTelemetry.h"
#include "modules/Telemetry/Sensor/TelemetrySensor.h"
#endif
#if HAS_TELEMETRY && !MESHTASTIC_EXCLUDE_POWER_TELEMETRY
#include "modules/Telemetry/PowerTelemetry.h"
#endif
#if !MESHTASTIC_EXCLUDE_GENERIC_THREAD_MODULE
#include "modules/GenericThreadModule.h"
#endif

#ifdef ARCH_ESP32
#if defined(USE_SX1280) && !MESHTASTIC_EXCLUDE_AUDIO
#include "modules/esp32/AudioModule.h"
#endif
#if !MESHTASTIC_EXCLUDE_PAXCOUNTER
#include "modules/esp32/PaxcounterModule.h"
#endif
#if !MESHTASTIC_EXCLUDE_STOREFORWARD
#include "modules/StoreForwardModule.h"
#endif
#endif
#if defined(ARCH_ESP32) || defined(ARCH_NRF52) || defined(ARCH_RP2040) || defined(ARCH_PORTDUINO)
#if !MESHTASTIC_EXCLUDE_EXTERNALNOTIFICATION
#include "modules/ExternalNotificationModule.h"
#endif
#if !MESHTASTIC_EXCLUDE_RANGETEST && !MESHTASTIC_EXCLUDE_GPS
#include "modules/RangeTestModule.h"
#endif
#if !defined(CONFIG_IDF_TARGET_ESP32S2) && !MESHTASTIC_EXCLUDE_SERIAL
#include "modules/SerialModule.h"
#endif
#endif

#if !MESHTASTIC_EXCLUDE_DROPZONE
#include "modules/DropzoneModule.h"
#endif

/**
 * Create module instances here.  If you are adding a new module, you must 'new' it here (or somewhere else)
 */
void setupModules()
{
        aqiReceiverModule = new AqiReceiverModule();
    if (config.device.role != meshtastic_Config_DeviceConfig_Role_REPEATER) {
#if (HAS_BUTTON || ARCH_PORTDUINO) && !MESHTASTIC_EXCLUDE_INPUTBROKER
        if (config.display.displaymode != meshtastic_Config_DisplayConfig_DisplayMode_COLOR) {
            inputBroker = new InputBroker();
            systemCommandsModule = new SystemCommandsModule();
            buzzerFeedbackThread = new BuzzerFeedbackThread();
        }
#endif
#if !MESHTASTIC_EXCLUDE_ADMIN
        adminModule = new AdminModule();
#endif
#if !MESHTASTIC_EXCLUDE_NODEINFO
        nodeInfoModule = new NodeInfoModule();
#endif
#if !MESHTASTIC_EXCLUDE_GPS
        positionModule = new PositionModule();
#endif
#if !MESHTASTIC_EXCLUDE_WAYPOINT
        waypointModule = new WaypointModule();
#endif
#if !MESHTASTIC_EXCLUDE_TEXTMESSAGE
        textMessageModule = new TextMessageModule();
#endif
#if !MESHTASTIC_EXCLUDE_TRACEROUTE
        traceRouteModule = new TraceRouteModule();
#endif
#if !MESHTASTIC_EXCLUDE_NEIGHBORINFO
        neighborInfoModule = new NeighborInfoModule();
#endif
#if !MESHTASTIC_EXCLUDE_DETECTIONSENSOR
        detectionSensorModule = new DetectionSensorModule();
#endif
#if !MESHTASTIC_EXCLUDE_ATAK
        atakPluginModule = new AtakPluginModule();
#endif
#if !MESHTASTIC_EXCLUDE_PKI
        keyVerificationModule = new KeyVerificationModule();
#endif
#if !MESHTASTIC_EXCLUDE_DROPZONE
        dropzoneModule = new DropzoneModule();
#endif
#if !MESHTASTIC_EXCLUDE_GENERIC_THREAD_MODULE
        new GenericThreadModule();
#endif
        // Note: if the rest of meshtastic doesn't need to explicitly use your module, you do not need to assign the instance
        // to a global variable.

#if !MESHTASTIC_EXCLUDE_REMOTEHARDWARE
        new RemoteHardwareModule();
#endif
#if !MESHTASTIC_EXCLUDE_POWERSTRESS
        new PowerStressModule();
#endif
        // Example: Put your module here
        // new ReplyModule();
#if (HAS_BUTTON || ARCH_PORTDUINO) && !MESHTASTIC_EXCLUDE_INPUTBROKER
        if (config.display.displaymode != meshtastic_Config_DisplayConfig_DisplayMode_COLOR) {
            rotaryEncoderInterruptImpl1 = new RotaryEncoderInterruptImpl1();
            if (!rotaryEncoderInterruptImpl1->init()) {
                delete rotaryEncoderInterruptImpl1;
                rotaryEncoderInterruptImpl1 = nullptr;
            }
            upDownInterruptImpl1 = new UpDownInterruptImpl1();
            if (!upDownInterruptImpl1->init()) {
                delete upDownInterruptImpl1;
                upDownInterruptImpl1 = nullptr;
            }
            cardKbI2cImpl = new CardKbI2cImpl();
            cardKbI2cImpl->init();
#ifdef INPUTBROKER_MATRIX_TYPE
            kbMatrixImpl = new KbMatrixImpl();
            kbMatrixImpl->init();
#endif // INPUTBROKER_MATRIX_TYPE
#ifdef INPUTBROKER_SERIAL_TYPE
            aSerialKeyboardImpl = new SerialKeyboardImpl();
            aSerialKeyboardImpl->init();
#endif // INPUTBROKER_MATRIX_TYPE
        }
#endif // HAS_BUTTON
#if ARCH_PORTDUINO
        if (config.display.displaymode != meshtastic_Config_DisplayConfig_DisplayMode_COLOR) {
            seesawRotary = new SeesawRotary("SeesawRotary");
            if (!seesawRotary->init()) {
                delete seesawRotary;
                seesawRotary = nullptr;
            }
            aLinuxInputImpl = new LinuxInputImpl();
            aLinuxInputImpl->init();
        }
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

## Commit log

2025-06-27 Circuit Diagram Added
2025-06-27 Added Gerber Files
    [bom.csv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]
2025-06-27 Added gerber
    [bom.csv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]
2025-06-30 Added CAD
    [base.stl, top.stl]
2025-07-02 Added .step
    [full.step]
